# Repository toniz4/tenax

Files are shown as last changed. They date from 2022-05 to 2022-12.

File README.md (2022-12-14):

# Tenax

Tenax is a direct pin/diodeless split keyboard, based on the Blackpill dev board. with pinkie splay.

## Pictures

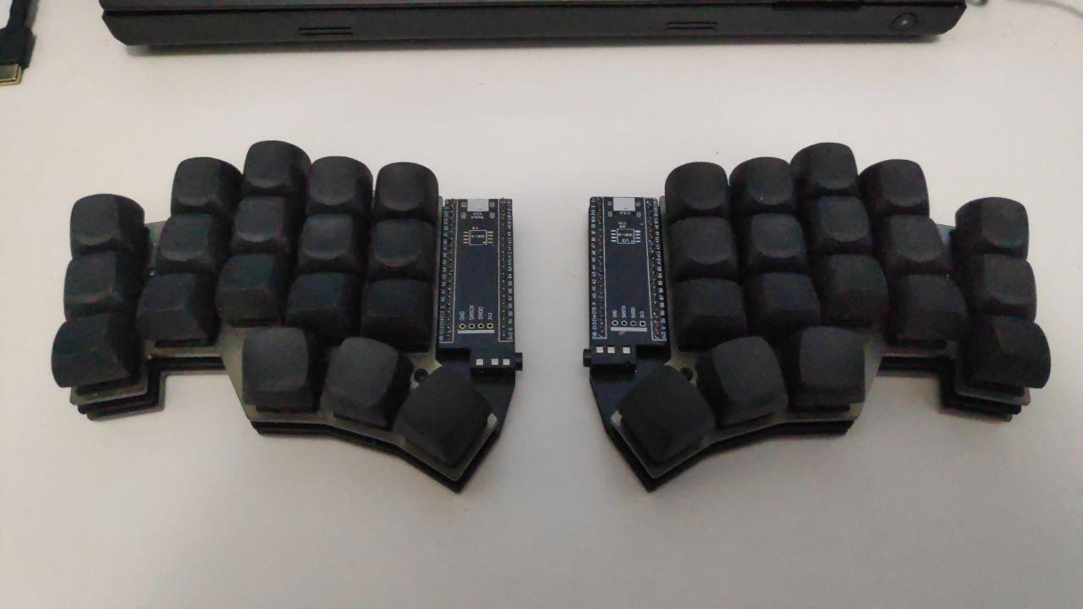
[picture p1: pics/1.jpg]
Overview

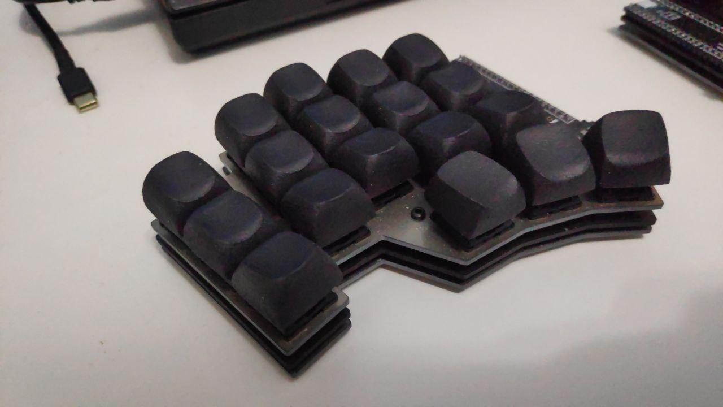
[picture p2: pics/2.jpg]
Close view


## Features

- No diodes
- Simple
  - No rgb
  - No oled
  - No buzzer (why someone would use this)
  - No having fun
- Cheap to build
- Moderate stagger
- Pinkie splay
- More memory, storage and clock than pro micro based boards
- Simple and comparatively fast to build

## Bill of Materials

| Component | Quantity | Comment |
|---|---|---|
| Blackpill | 2 | [Weact Blackpills](https://pt.aliexpress.com/item/1005001456186625.html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) |
| (Optional) Round socket headers | 4 pieces with 20 slots | [Sockets](https://pt.aliexpress.com/item/32849903666.html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) |
| PCB | 2 | [JLCPCB](https://jlcpcb.com/) |
| PJ-320A TRRS Jack | 2 | [TRRS Jack](https://pt.aliexpress.com/item/33029465106.html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) |
| Plates | 2 bottom plates 2 top plates | file ready to production in ./production/case/tenax-plates.dxf |
| 3mm M2 screws | 20 | [Screws](https://pt.aliexpress.com/item/32810852732.html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) |
| 8mm M2 standoffs | 10 | [Standoffs](https://pt.aliexpress.com/item/1005001478740318.html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) |
| Hotswap sockets | 36 | [Kailh Hotswap sockets](https://pt.aliexpress.com/item/4001051840976.html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) |
| Switches | 36 | Any MX compatible switch will work |

## Build Guide

I'm too lazy to create a build guide, but the cantor keyboard build is similar, so it can
be used as reference, together with the hotswap sockets part on the corne guide.

- [Cantor guide](https://github.com/diepala/cantor/blob/main/doc/build_guide.md)
- [How to solder the hotswap sockets](https://github.com/foostan/crkbd/blob/main/corne-cherry/doc/v2/buildguide_en.md#kailh-pcb-socket)

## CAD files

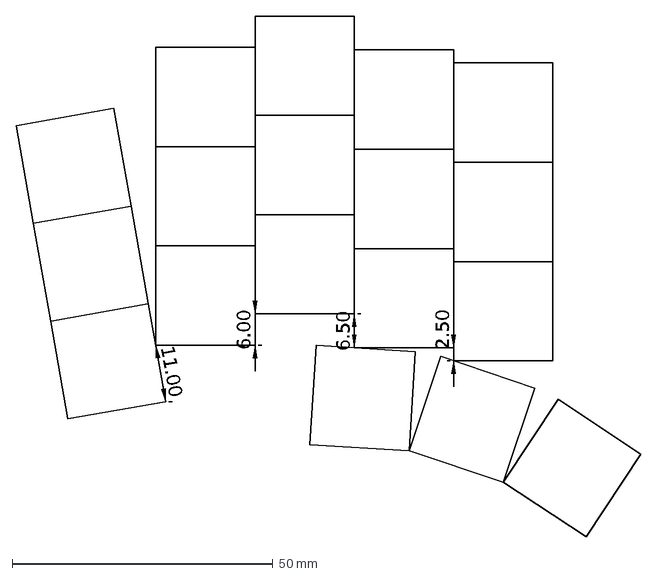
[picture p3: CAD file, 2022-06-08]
cad/plates/#tenax-KeyPositionsKeyPos.dxf
2.50
6.50
6.00
11.00

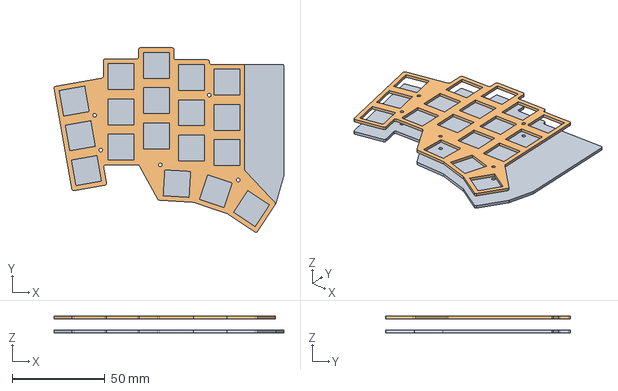
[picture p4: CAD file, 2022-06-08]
cad/tenax.FCStd
124.0 x 99.6 x 9.00 mm
Bottom Plate
Top Plate

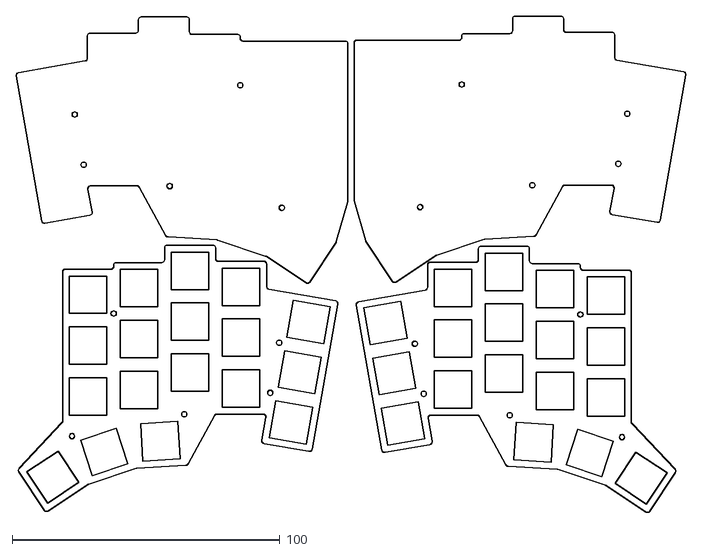
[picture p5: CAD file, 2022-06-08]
production/case/tenax-plates.dxf
250.5 x 185.7

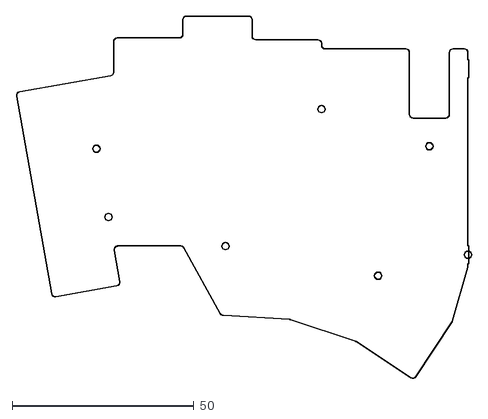
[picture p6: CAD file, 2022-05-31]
cad/plates/tenax-PanelSketch002.dxf
125.1 x 99.7

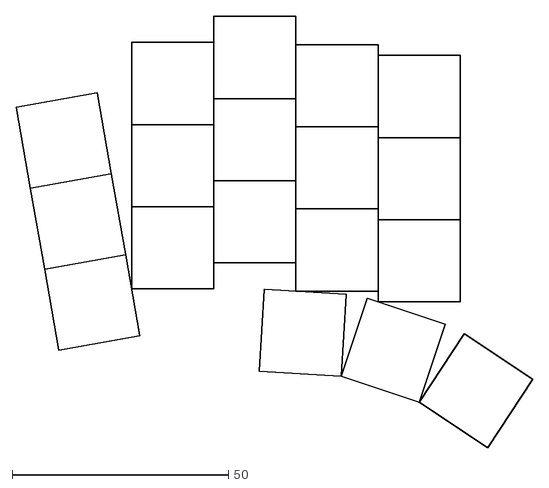
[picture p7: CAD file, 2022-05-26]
cad/tenax-KeyPositionsKeyPos.dxf
119.5 x 99.7

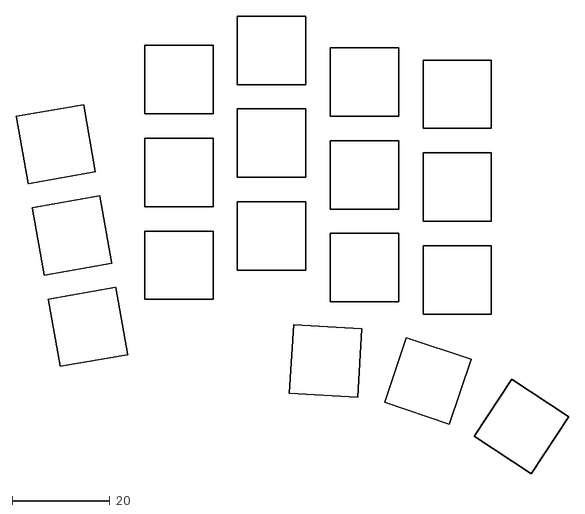
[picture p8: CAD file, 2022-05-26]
cad/plates/tenax-Body001Sketch001.dxf
113.1 x 93.7

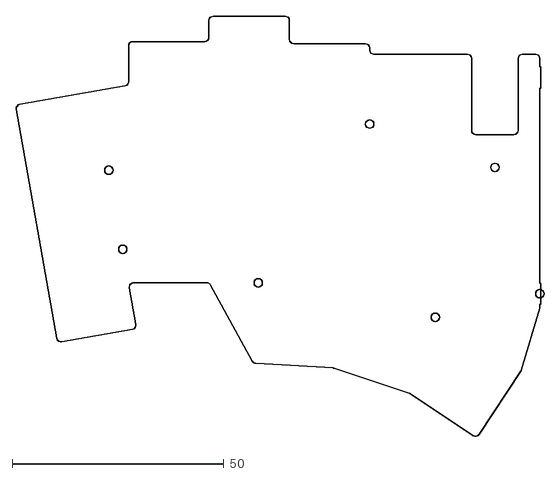
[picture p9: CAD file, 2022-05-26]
cad/tenax-PanelSketch002.dxf
124.8 x 99.4

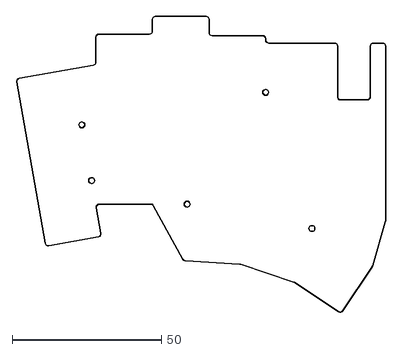
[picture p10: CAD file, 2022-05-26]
cad/plates/tenax-Bottom PlateSketch003.dxf
123.8 x 99.4

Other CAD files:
cad/plates/tenax-KeyPositionsKeyPos.dxf

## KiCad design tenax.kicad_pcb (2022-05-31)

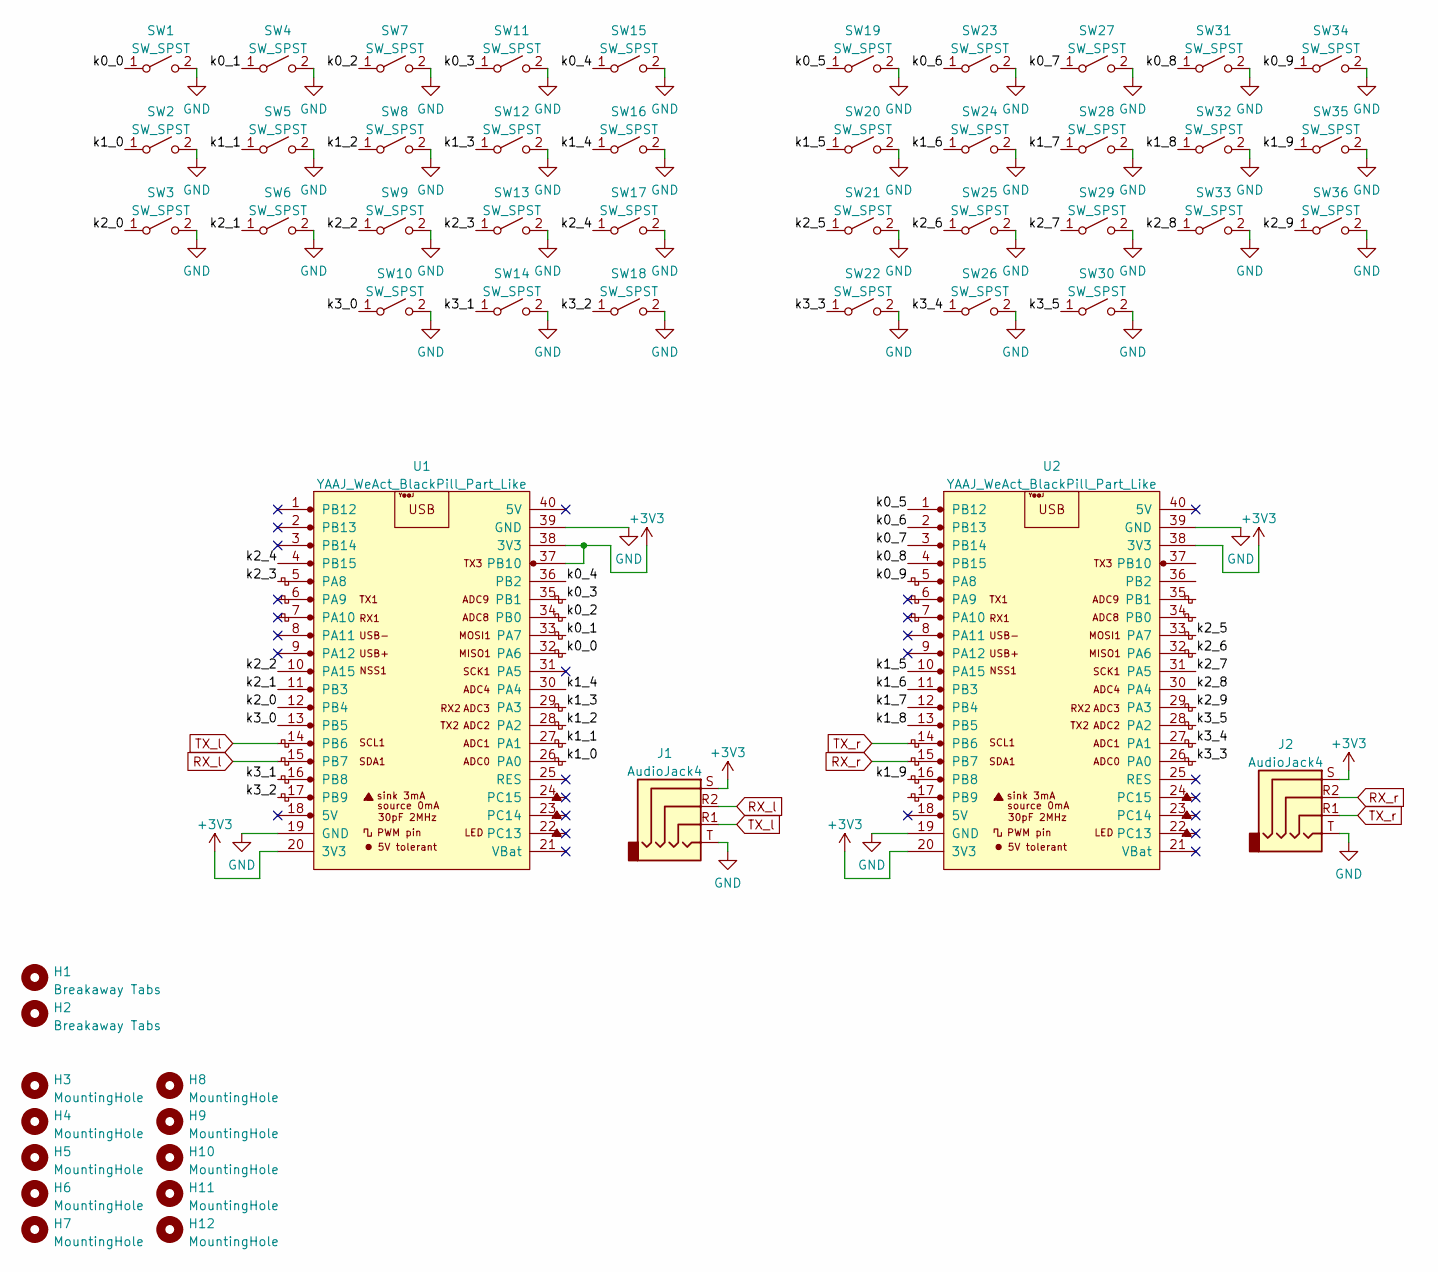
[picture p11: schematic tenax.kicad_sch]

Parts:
H1, H2: Breakaway Tabs; Breakaway_Tabs
H3, H4, H5, H6, H7, H8, H9, H10, H11, H12: MountingHole; M2_HOLE_v2
J1, J2: AudioJack4; MJ-4PP-9_1side
SW1, SW2, SW3, SW4, SW5, SW6, SW7, SW8, SW9, SW10, SW11, SW12, SW13, SW14, SW15, SW16, SW17, SW18, SW19, SW20, SW21, SW22, SW23, SW24, SW25, SW26, SW27, SW28, SW29, SW30, SW31, SW32, SW33, SW34, SW35, SW36: SW_SPST; CherryMX_Hotswap
U1, U2: YAAJ_WeAct_BlackPill_Part_Like; BlackPill_STLINK

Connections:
+3V3: J1.S, J2.S, U1.20 (3V3), U1.37 (PB10), U1.38 (3V3), U2.20 (3V3), U2.38 (3V3)
/k0_0: SW1.1 (A), U1.32 (PA6)
/k0_1: SW4.1 (A), U1.33 (PA7)
/k0_2: SW7.1 (A), U1.34 (PB0)
/k0_3: SW11.1 (A), U1.35 (PB1)
/k0_4: SW15.1 (A), U1.36 (PB2)
/k0_5: SW19.1 (A), U2.1 (PB12)
/k0_6: SW23.1 (A), U2.2 (PB13)
/k0_7: SW27.1 (A), U2.3 (PB14)
/k0_8: SW31.1 (A), U2.4 (PB15)
/k0_9: SW34.1 (A), U2.5 (PA8)
/k1_0: SW2.1 (A), U1.26 (PA0)
/k1_1: SW5.1 (A), U1.27 (PA1)
/k1_2: SW8.1 (A), U1.28 (PA2)
/k1_3: SW12.1 (A), U1.29 (PA3)
/k1_4: SW16.1 (A), U1.30 (PA4)
/k1_5: SW20.1 (A), U2.10 (PA15)
/k1_6: SW24.1 (A), U2.11 (PB3)
/k1_7: SW28.1 (A), U2.12 (PB4)
/k1_8: SW32.1 (A), U2.13 (PB5)
/k1_9: SW35.1 (A), U2.16 (PB8)
/k2_0: SW3.1 (A), U1.12 (PB4)
/k2_1: SW6.1 (A), U1.11 (PB3)
/k2_2: SW9.1 (A), U1.10 (PA15)
/k2_3: SW13.1 (A), U1.5 (PA8)
/k2_4: SW17.1 (A), U1.4 (PB15)
/k2_5: SW21.1 (A), U2.33 (PA7)
/k2_6: SW25.1 (A), U2.32 (PA6)
/k2_7: SW29.1 (A), U2.31 (PA5)
/k2_8: SW33.1 (A), U2.30 (PA4)
/k2_9: SW36.1 (A), U2.29 (PA3)
/k3_0: SW10.1 (A), U1.13 (PB5)
/k3_1: SW14.1 (A), U1.16 (PB8)
/k3_2: SW18.1 (A), U1.17 (PB9)
/k3_3: SW22.1 (A), U2.26 (PA0)
/k3_4: SW26.1 (A), U2.27 (PA1)
/k3_5: SW30.1 (A), U2.28 (PA2)
GND: J1.T, J2.T, SW1.2 (B), SW2.2 (B), SW3.2 (B), SW4.2 (B), SW5.2 (B), SW6.2 (B), SW7.2 (B), SW8.2 (B), SW9.2 (B), SW10.2 (B), SW11.2 (B), SW12.2 (B), SW13.2 (B), SW14.2 (B), SW15.2 (B), SW16.2 (B), SW17.2 (B), SW18.2 (B), SW19.2 (B), SW20.2 (B), SW21.2 (B), SW22.2 (B), SW23.2 (B), SW24.2 (B), SW25.2 (B), SW26.2 (B), SW27.2 (B), SW28.2 (B), SW29.2 (B), SW30.2 (B), SW31.2 (B), SW32.2 (B), SW33.2 (B), SW34.2 (B), SW35.2 (B), SW36.2 (B), U1.19 (GND), U1.39 (GND), U2.19 (GND), U2.39 (GND)
RX_l: J1.R2, U1.15 (PB7)
RX_r: J2.R2, U2.15 (PB7)
TX_l: J1.R1, U1.14 (PB6)
TX_r: J2.R1, U2.14 (PB6)

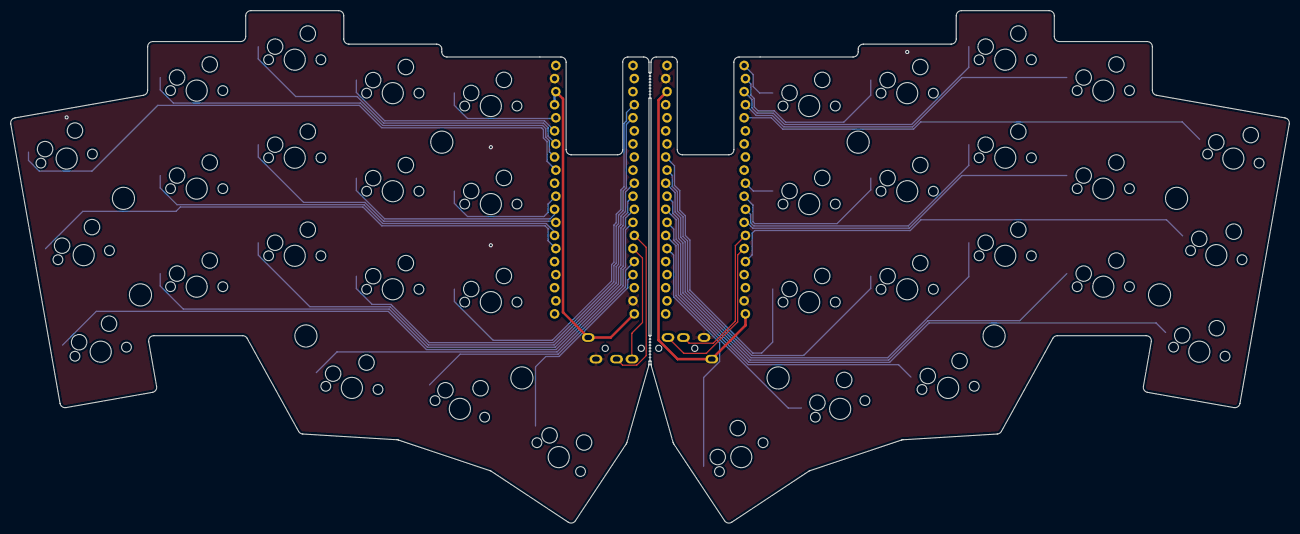
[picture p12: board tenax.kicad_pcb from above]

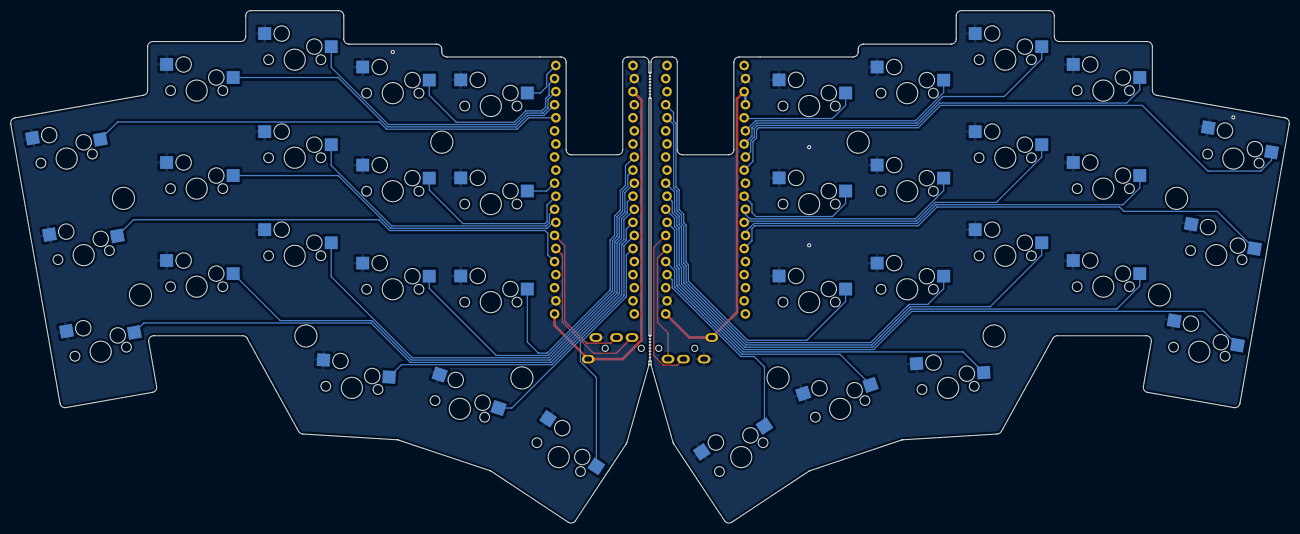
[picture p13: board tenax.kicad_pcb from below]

Board: 2 copper layers, 248.4 x 99.5 mm, 52 parts (2 on the bottom side), 42 nets.

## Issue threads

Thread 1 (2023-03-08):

Where can I find the firmware?

chewiedies, 2023-03-08:
I have ordered the PCBs and built the first pair, but I can't find the firmware.

toniz4, 2023-03-08:
Forgot to push to my qmk fork, sorry about that. Tomorrow I will do that in the morning. Here is 2:00am currently.

But for testing, you can use the same cantor firmware, with some changes to the pin definitions.

chewiedies, 2023-03-08:
No worries! Thanks for the quick response. I flashed the Cantor firmware already. It works to test out the matrix, even though the rows/cols are different. But split comms didn't work at all with the Cantor .bin file.

toniz4, 2023-03-08:
> No worries! Thanks for the quick response. I flashed the Cantor firmware already. It works to test out the matrix, even though the rows/cols are different. But split comms didn't work at all with the Cantor .bin file.

https://github.com/toniz4/qmk_firmware/

try It out with my fork.

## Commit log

2022-05-31 Last detais
    [tenax-Body001Sketch001.dxf, tenax-Bottom PlateSketch003.dxf, tenax-PanelSketch002.dxf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]
2022-06-08 production version, fixed switch connected to B2
    [#tenax-KeyPositionsKeyPos.dxf, tenax-B_Cu.gbl, tenax-B_Mask.gbs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]
2022-09-24 fixed pcb
    [tenax-B_Cu.gbl, tenax-B_Mask.gbs, tenax-B_Paste.gbp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]
2022-09-28 fix quantity off standoffs
